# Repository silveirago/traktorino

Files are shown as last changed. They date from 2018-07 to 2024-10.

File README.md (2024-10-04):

# Traktorino

Welcome to the Traktorino project! The Traktorino is a low-cost, DIY MIDI controller for DJs. It can control any software that accepts MIDI, such as Traktor, Serato, or Ableton Live. This project is open-source, so you can download all the files for the schematics, enclosure, and code to build one yourself.

## Table of Contents
- [Introduction](#introduction)
- [Parts List](#parts-list)
- [Assembly Instructions](#assembly-instructions)
- [Programming the Arduino](#programming-the-arduino)
- [Setting Up MIDI](#setting-up-midi)
- [Enclosure Assembly](#enclosure-assembly)
- [Troubleshooting](#troubleshooting)
- [Support and Contributions](#support-and-contributions)

## Introduction
Watch the video series on how to build your Traktorino:
1. [Video 1: Introduction and Assembly](https://youtu.be/pawsvbFrXVM)
2. [Video 2: Programming the Arduino](https://youtu.be/B8oFYNJLdgw)
3. [Video 3: Setting Up MIDI](https://youtu.be/18OKo9sQ_s0)
4. [Video 4: Enclosure Assembly](https://youtu.be/xLqzVqaUnkY)

## Parts List
- 1x Traktorino PCB
- 1x Arduino Uno ATmega16U2
- 11x b10k vertical rotary pots
- 3x b10k slide pots - 45mm - 30mm travel (C3031N-1A2-B10K-GP)
- 1x Rotary Encoder
- 2x cd4067 be multiplexers
- 3x 74hc595 bit shifters
- 13x tactile buttons 6x6x9
- 24x 220ohm resistors 
- 1x 1k resistor
- 11x 3mm blue leds 
- 10x 3mm green leds
- 2x 3mm yellow leds
- 2x 3mm red leds

### Parts suggestion

- **Pot 25mm**
https://lcsc.com/product-detail/Potentiometers-Variable-Resistors_ALPS-Electric-RK09D1130C2P_C361173.html

- **Encoder 25mm**
https://www.mouser.com/ProductDetail/Bourns/PEC12R-4025F-N0024?qs=Zq5ylnUbLm4HSBD7%2FFgU%2FA%3D%3D

- **Encoder 20mm**
https://www.mouser.com/ProductDetail/Bourns/PEC11H-4120F-S0020?qs=7MVldsJ5Uaxh8cksqYCfvg%3D%3D 20mm

- **Slide Pot**
https://www.sparkfun.com/products/11621

## Assembly Instructions
1. **Resistors**: Insert and solder the 220 ohm resistors. Place a 1k resistor in the specified position.
2. **Arduino Pin Headers**: Solder the pin headers to the Arduino and snap it onto the PCB.
3. **Multiplexers and Bit Shifters**: Solder these components onto the PCB.
4. **LEDs**: Ensure correct polarity and solder the LEDs.
5. **Tactile Buttons**: Solder the tactile buttons, ensuring correct orientation.
6. **Potentiometers**: Solder the slide and rotary potentiometers.
7. **Rotary Encoder**: Solder the rotary encoder.

## Programming the Arduino
1. Download and install the [Arduino IDE](https://www.arduino.cc/en/software).
2. Clone the Traktorino GitHub repository: `git clone https://github.com/your-repo/traktorino`.
3. Open the Arduino IDE and load the Traktorino code.
4. Install the required libraries: ShiftPWM, MIDI, Multiplexer4067, Thread, and Encoder.
5. Verify the code and upload it to the Arduino Uno.

## Setting Up MIDI
1. **USB MIDI Compatibility**: Use an Arduino Uno with the ATmega16U2 for true USB MIDI compatibility.
2. **DFU Programmer**: Download and install the DFU programmer.
3. **Upload Firmware**: Use the provided `.hex` file to flash the firmware to the ATmega16U2.
4. **Test MIDI**: Use a DAW or MIDI monitoring software to test the MIDI signals from the Traktorino.

## Enclosure Assembly
1. Assemble the plywood enclosure using the provided PDF files.
2. Install the diffusers, spacers, and screws as specified.
3. Attach the button caps and potentiometer knobs.

## Troubleshooting
- If the Traktorino is not functioning, use a multimeter to check for connectivity issues.
- Verify that all components are correctly soldered and oriented.

## Support and Contributions
- Subscribe to the [YouTube channel](https://www.youtube.com/channel/UCyqCwyBJ98fR-CPoyXUxY5w) for updates and tutorials.
- Purchase a Traktorino kit from our store. (Out of stock)
- Check out the [DIY MIDI Controller Workshop](https://go.musiconerd.com/diy-midi-controller-workshop) for more in-depth learning.

## Code Explanation

### PWM Bit Shifter
The code uses a PWM bit shifter for controlling LEDs:
- `ShiftPWM_latchPin`: Set to pin 8.
- To avoid using the SPI port and change the pin numbers, uncomment `#define SHIFTPWM_NOSPI` and set `ShiftPWM_dataPin` and `ShiftPWM_clockPin`.
- `ShiftPWM_invertOutputs`: Set to `false`. Change to `true` if your LEDs turn on when the pin is low.
- `ShiftPWM_balanceLoad`: Set to `false`. Set to `true` to distribute current peaks.

### Libraries
The following libraries are included:
- **ShiftPWM** for PWM control.
- **MIDI** by Forty Seven Effects for MIDI communication.
- **Multiplexer4067** for handling the CD4067 multiplexer.
- **Thread** and **ThreadController** by Ivan Seidel for managing multiple tasks.
- **Encoder** by Paul Stoffregen for handling rotary encoders.

### Buttons
- `muxNButtons`: Number of digital inputs used in the multiplexer.
- `NButtons`: Number of direct digital inputs used.
- `muxButtonPin` and `buttonPin`: Arrays to store the pins used for buttons.

### Debounce
- `lastDebounceTime` and `debounceDelay`: Used to handle debounce for button presses.

### Potentiometers
- `NPots`: Number of analog inputs used.
- `muxPotPin`: Array to store the pins used for potentiometers.

### Potentiometer Reading
- `TIMEOUT`: Time the potentiometer will be read after exceeding `varThreshold`.
- `varThreshold`: Threshold for potentiometer signal variation.

### Encoder
- `myEnc`: Instance of the `Encoder` library using pins 3 and 2.
- `oldPosition`: Previous position of the encoder.

### MIDI Configuration
- `midiCh`, `note`, and `cc`: MIDI channel, note, and CC configurations.

### LEDs
- Configuration for controlling 24 LEDs with PWM.
- VU meter and button LED pins are defined.

### Multiplexer
- Instances of `Multiplexer4067` for pots and buttons.

### Threads
- `ThreadController` for managing tasks.
- Separate threads for reading potentiometers and buttons.

### Setup and Loop
In `setup()`, the serial communication is initialized, MIDI thru is turned off, multiplexers and LEDs are initialized, and threads are configured.

In `loop()`, the main tasks such as reading MIDI, encoder, and running threads are handled.

### Functions
- `readButtons()`: Reads button states and sends MIDI note messages.
- `readPots()`: Reads potentiometer states and sends MIDI control change messages.
- `readEncoder()`: Reads encoder values and sends MIDI control change messages.
- `handleControlChange()`, `handleNoteOn()`, and `handleNoteOff()`: Handle LED feedback for MIDI control changes and note messages.

## Usage
- Connect your Arduino and load the provided code.
- Ensure all components (buttons, potentiometers, LEDs) are connected to the specified pins.
- Install the required libraries mentioned above.
- Upload the code to your Arduino and start using your Traktorino MIDI controller with your favorite DJ software.

Feel free to modify the code and configurations to fit your specific needs. Happy DJing!

---

**Author**: Gustavo Silveira

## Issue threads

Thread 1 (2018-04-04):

Electronics sources

jvegaf, 2018-04-04:
Hi, can you add the electronics source project files on the project ?

Thanks !

ivnagst, 2018-05-15:
The project is awesome... But if you include more 2 channels and effects options... Removes the horizontal fadder, input microphone plug, master volume...

jvegaf, 2018-05-15:
maybe fork the project and through reverse engineering we could get the schematics

silveirago, 2018-05-17:
I will work more on it on July and will release a more complete material of
it!

2018-05-15 5:27 GMT-07:00 Jose Vega <notifications@github.com>:

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

--
Gustavo Silveira
Composer / Multimedia Artist
www.gustavosilveira.net

ameer157, 2018-05-17:
@silveirago I already managed to switch to the MidiUSB library and add multiple encoders as well as receiving 'MIDI Out' feedback from Traktor to light up LEDs 👍

stroblme, 2019-05-25:
Hi, anything new regarding the source files?

jvegaf, 2019-06-02:
> Hi, anything new regarding the source files?

the guy missed us, don't believe that releease the electronic source files....

jvegaf, 2021-01-31:
Thanks @silveirago

Closed 2021-01-31.

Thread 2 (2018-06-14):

Add Bill of Material and PCB project source files

sebastianeferrer, 2018-06-14:
Hi, it is great project I would like to colaborate it would be great if you share PCB project source files if not I can help you to export it to an open source software like kicad. Thank you again for sharing this with us!

silveirago, 2018-06-14:
Hi, I'm still bring in the project, that's why I didn't release everything
properly. I hope to have everything, plus tutorials by August. So, may I
contact you later for help with that?

2018-06-13 21:51 GMT-04:00 sebastianeferrer <notifications@github.com>:

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

--
Gustavo Silveira
Composer / Multimedia Artist
www.gustavosilveira.net

sebastianeferrer, 2018-06-15:
Yes, of course! It would be a pleasure.

DanBendavid, 2018-06-30:
Ciao Silvio
Dan here. Your project is so elegant and very powerful. I have one question regarding the encoder.
You have not included a debouncing hardware (i.e., C10nF and R10KO) ? is that because the MIDI has its own debouncing "mechanism" ?
Gracie mille for making this Open.

silveirago, 2018-06-30:
Hi, the Encoder library is really good and takes care of it. It works pretty flawlessly!

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

spotlesscoder, 2025-03-16:
can this issue be closed now?

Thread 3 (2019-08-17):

Mixxx profile

arthurlutz, 2019-08-17:
It would be nice to be able to use traktorino with a Mixxx https://www.mixxx.org/ the open source DJ software.

I've started a profile by detecting the Input Mapping, but am having trouble with the output mapping (turn on and off LEDs)

arthurlutz, 2019-08-17:
Here is  the "initial" config file I've started : https://gist.github.com/arthurlutz/25ea0970a9d26ba0394d54f1b79cdaea

Put it in `$HOME/.mixxx/controllers/`

arthurlutz, 2019-08-17:
Here is the Mixxx documentation for this mapping, https://mixxx.org/wiki/doku.php/midi_controller_mapping_file_format

Unfortunatelly the Traktor XML file https://github.com/silveirago/traktorino/blob/master/Traktor/Traktorino.tsi is unreadable, I was hoping to get information from there. If anyone has a way to decrypt/decode it, that would be greate, or a screenshot of the configuration in traktor would be nice too.

WieFel, 2019-09-28:
Thanks for your config!
I have the exact same problem. My LEDs are not lighting up.

Additionally, my faders are not working properly when trying to "learn" them with Mixxx. E.g. when the physical fader is positioned exactly in the center, the fader in Mixxx is quite far on the left side... I don't know if that is related to the potentiometers I used or to Mixxx. Have you experienced similar problems?

dulouie, 2020-11-10:
Hi guys, I created a javascript profile for Mixxx some time ago. All sliders, pots and also the LEDs work. Unfortunately there are still a few bugs. For example, sometimes you have to click into the list again when selecting a song. I hope I will have more time to develop further soon.
https://github.com/dulouie/traktorino/tree/mixxxscript/Mixxx

arthurlutz, 2020-11-11:
Awesome @dulouie it works great ! (not sure what what "shift" does, and filter on/off seems to not work in my setup)

To get it working I had to `cp Traktorino.midi.xml ~/.mixxx/controllers/Traktorino_MIDI_1.midi.xml` (not sure why it needs the `_MIDI_1` addition).

I think these files should be shipped directly with Mixxx so traktorino works out of the box, how would you feel about submitting them to https://github.com/mixxxdj/mixxx/tree/main/res/controllers ? Do you  want help with that ?

dulouie, 2020-11-14:
I think the shift-button allows a double assignment of the other buttons, you can theoretically control 4 decks, but I don't use it.
Yes, I noticed the "_MIDI_1" but I have no idea why it only works with that.
My goal is also a pull request to Mixx, but I want to fix the remaining bugs and clean up a bit, the logic to create the decks is not quite clean yet. If you like you can help me. I have the new branch for a PR here:
https://github.com/dulouie/mixxx/tree/traktorino/

WieFel, 2020-11-14:
@arthurlutz @dulouie really cool guys!! 👏🏼

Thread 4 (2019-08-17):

Provide test code (MIDI or Arduino) to test out the LEDs once the assembly is finished

arthurlutz, 2019-08-17:
Once the assembly is finished it would be nice to have a test program to test out all the LEDs, two solutions could be used :

* some sort of python script or other that talks to midi and turns on and off the LEDs by sending MIDI signales

* an arduino sketch that goes through all the LEDs and turns them on and off and prints out some debug information on the serial port.

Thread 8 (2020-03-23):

MIDI Input gets echoed onto MIDI Output, create infinite send/receive loop in dj software

rasprague, 2020-03-23:
CC messages on MIDI Input are being echoed back out onto MIDI Output. This causes an infinite send/receive loop in the dj software.

Issue recreated in DJ Player Pro on iOS during led CC mapping.

Issue recreated in MIDI-OX on Windows 10, when both Traktorino MIDI Input and Output are opened

rasprague, 2020-03-24:
I think I fixed this one, check put pull request https://github.com/silveirago/traktorino/pull/12

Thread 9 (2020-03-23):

Browse Encode click not mapped to any MIDI output message

rasprague, 2020-03-23:
Clicking the Browse encoder does not result in a MIDI message being send out.

Is the encoder click currently wired to a pin via the PCB? If so, where does it go? If not, a possible workaround would to be to wire it up to a free digital pin on the Arduino (hacking!), and read that digital pin from the code.

rasprague, 2020-03-24:
got it working!

pull reqeust https://github.com/silveirago/traktorino/pull/11

Gypsyocruzz, 2023-04-02:
hello rasprague. Im making this porject can you tell me if you also had shots in the pcb or components? Cos in the traktor software the pots and others others components doesnt stops to send midi signals. So i cant control the controller in a proper way

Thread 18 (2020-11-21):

Issues with some pots and midi data range

edy80y, 2020-11-21:
Hi All,

I've just built a Traktorino from scratch and as per the title I need help.

1. The following potentiometers are not registering:
- Ch1 fader
- Ch2 gain
- Ch2 eq high
- Ch2 eq mid

2. Using Midi Monitor, the working pots have data values ranging between 64-126 (i.e. only 50% range).  In other words the entire range of the potentiometers are only effecting from centre to max, and this translates the same way in Traktor Pro, for example: Turning Ch1 Eq Low only moves between centre and max, Ch2 fader only moves from 50% to 100% in the software.

I noticed at the bottom of the PCB there are points for test (continuity etc?).  Is there any documentation on how to use them and what values to expect during trouble shooting? I do own a multimeter, and any help would be appreciated.

lastly, what's the best way to reduce the brightness of the leds? Can i replace the resisters with a higher value?

Cheers,
Eddie

Gypsyocruzz, 2023-04-02:
hello. Im making this porject can you tell me if you also had shots in the pcb or components? Cos in the traktor software the pots and others others components doesnt stops to send midi signals. So i cant control the controller in a proper way

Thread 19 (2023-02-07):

MIDI ERROR IN CODE, PLS NEED HELP

JotaMichas, 2023-02-07:
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

D:\Arduino\traktorino-master\Code\Traktorino\Traktorino.ino: In function 'void setup()':
D:\Arduino\traktorino-master\Code\Traktorino\Traktorino.ino:115:3: error: 'MIDI' was not declared in this scope
   MIDI.turnThruOff();
   ^~~~
D:\Arduino\traktorino-master\Code\Traktorino\Traktorino.ino:115:3: note: suggested alternative: 'MISO'
   MIDI.turnThruOff();
   ^~~~
   MISO
D:\Arduino\traktorino-master\Code\Traktorino\Traktorino.ino: In function 'void loop()':
D:\Arduino\traktorino-master\Code\Traktorino\Traktorino.ino:176:3: error: 'MIDI' was not declared in this scope
   MIDI.read();
   ^~~~
D:\Arduino\traktorino-master\Code\Traktorino\Traktorino.ino:176:3: note: suggested alternative: 'MISO'
   MIDI.read();
   ^~~~
   MISO
D:\Arduino\traktorino-master\Code\Traktorino\Traktorino.ino: In function 'void readButtons()':
D:\Arduino\traktorino-master\Code\Traktorino\Traktorino.ino:214:11: error: 'MIDI' was not declared in this scope
           MIDI.sendNoteOn(note + i, 127, midiCh); // envia NoteOn(nota, velocity, canal midi)
           ^~~~
D:\Arduino\traktorino-master\Code\Traktorino\Traktorino.ino:214:11: note: suggested alternative: 'MISO'
           MIDI.sendNoteOn(note + i, 127, midiCh); // envia NoteOn(nota, velocity, canal midi)
           ^~~~
           MISO
D:\Arduino\traktorino-master\Code\Traktorino\Traktorino.ino:221:11: error: 'MIDI' was not declared in this scope
           MIDI.sendNoteOn(note + i, 0, midiCh);
           ^~~~
D:\Arduino\traktorino-master\Code\Traktorino\Traktorino.ino:221:11: note: suggested alternative: 'MISO'
           MIDI.sendNoteOn(note + i, 0, midiCh);
           ^~~~
           MISO
D:\Arduino\traktorino-master\Code\Traktorino\Traktorino.ino: In function 'void readPots()':
D:\Arduino\traktorino-master\Code\Traktorino\Traktorino.ino:261:9: error: 'MIDI' was not declared in this scope
         MIDI.sendControlChange(cc + i, map(potCState[i], 0, 1023, 0, 127), 11); // envia Control Change (numero do CC, valor do CC, canal midi)
         ^~~~
D:\Arduino\traktorino-master\Code\Traktorino\Traktorino.ino:261:9: note: suggested alternative: 'MISO'
         MIDI.sendControlChange(cc + i, map(potCState[i], 0, 1023, 0, 127), 11); // envia Control Change (numero do CC, valor do CC, canal midi)
         ^~~~
         MISO
D:\Arduino\traktorino-master\Code\Traktorino\Traktorino.ino: In function 'void readEncoder()':
D:\Arduino\traktorino-master\Code\Traktorino\Traktorino.ino:288:5: error: 'MIDI' was not declared in this scope
     MIDI.sendControlChange(14, encoderValue, 1);
     ^~~~
D:\Arduino\traktorino-master\Code\Traktorino\Traktorino.ino:288:5: note: suggested alternative: 'MISO'
     MIDI.sendControlChange(14, encoderValue, 1);
     ^~~~
     MISO
Multiple libraries were found for "MIDI.h"
  Used: C:\Users\Jota\Documents\Arduino\libraries\MIDI_Library
  Not used: C:\Users\Jota\Documents\Arduino\libraries\arduino_midi_library-master
exit status 1

Compilation error: 'MIDI' was not declared in this scope

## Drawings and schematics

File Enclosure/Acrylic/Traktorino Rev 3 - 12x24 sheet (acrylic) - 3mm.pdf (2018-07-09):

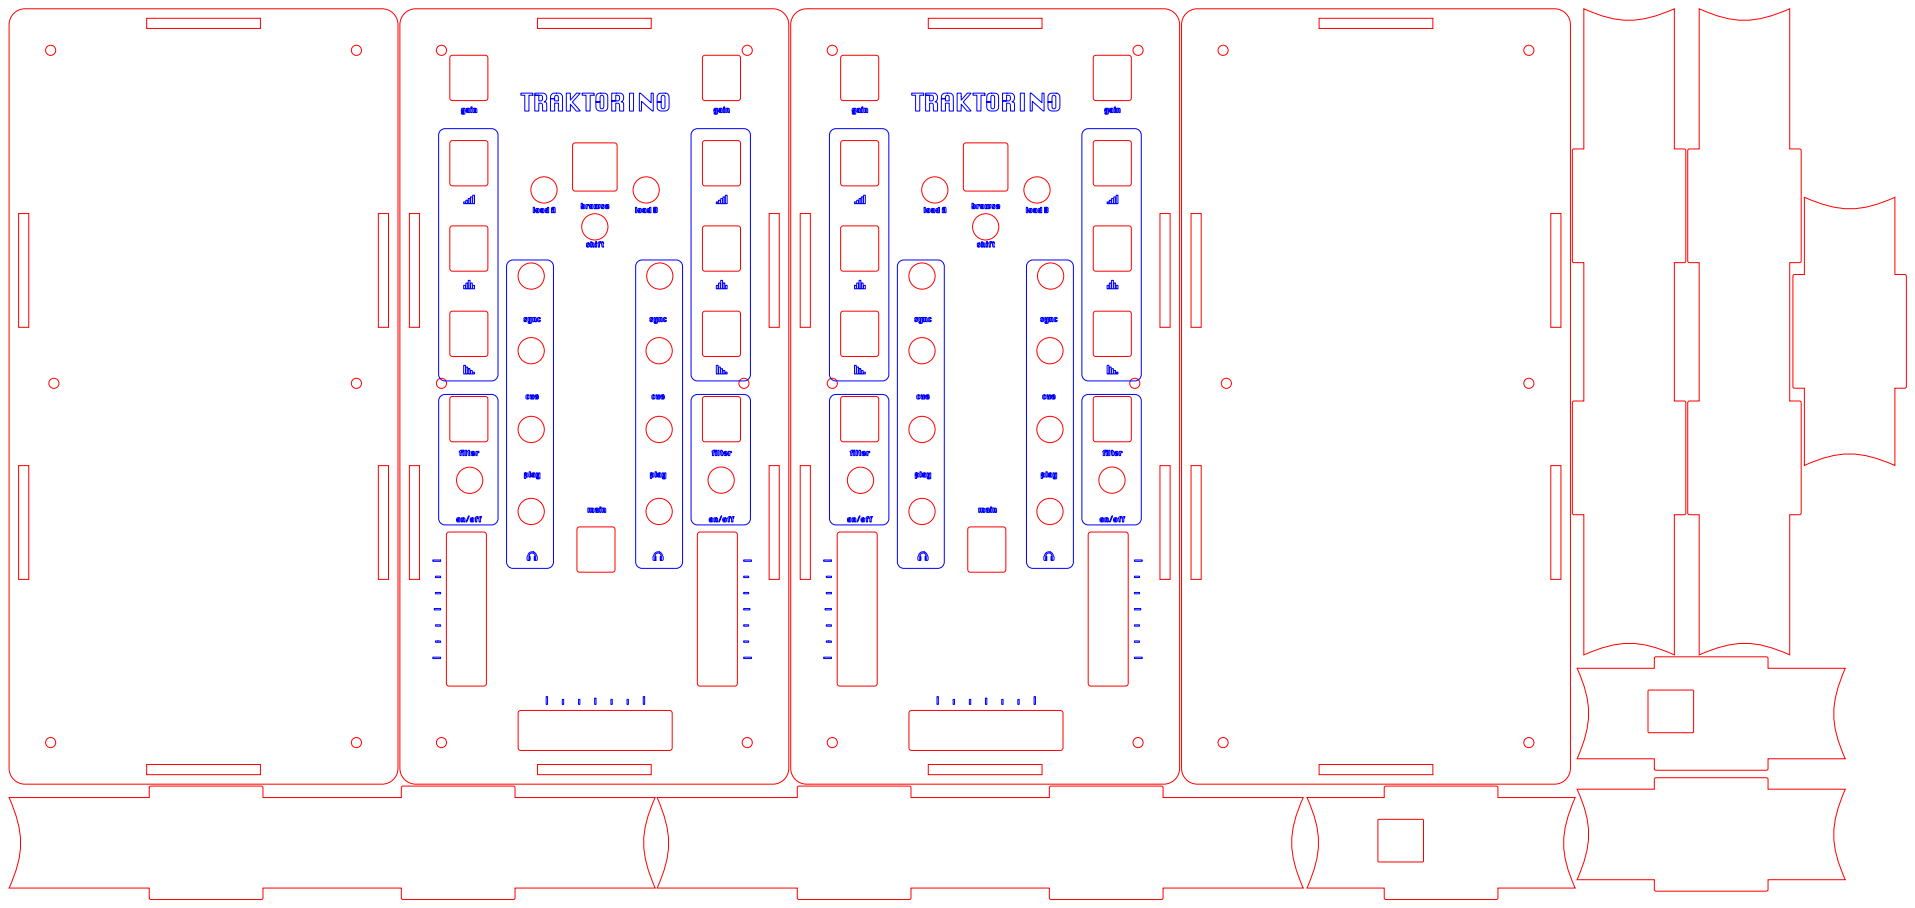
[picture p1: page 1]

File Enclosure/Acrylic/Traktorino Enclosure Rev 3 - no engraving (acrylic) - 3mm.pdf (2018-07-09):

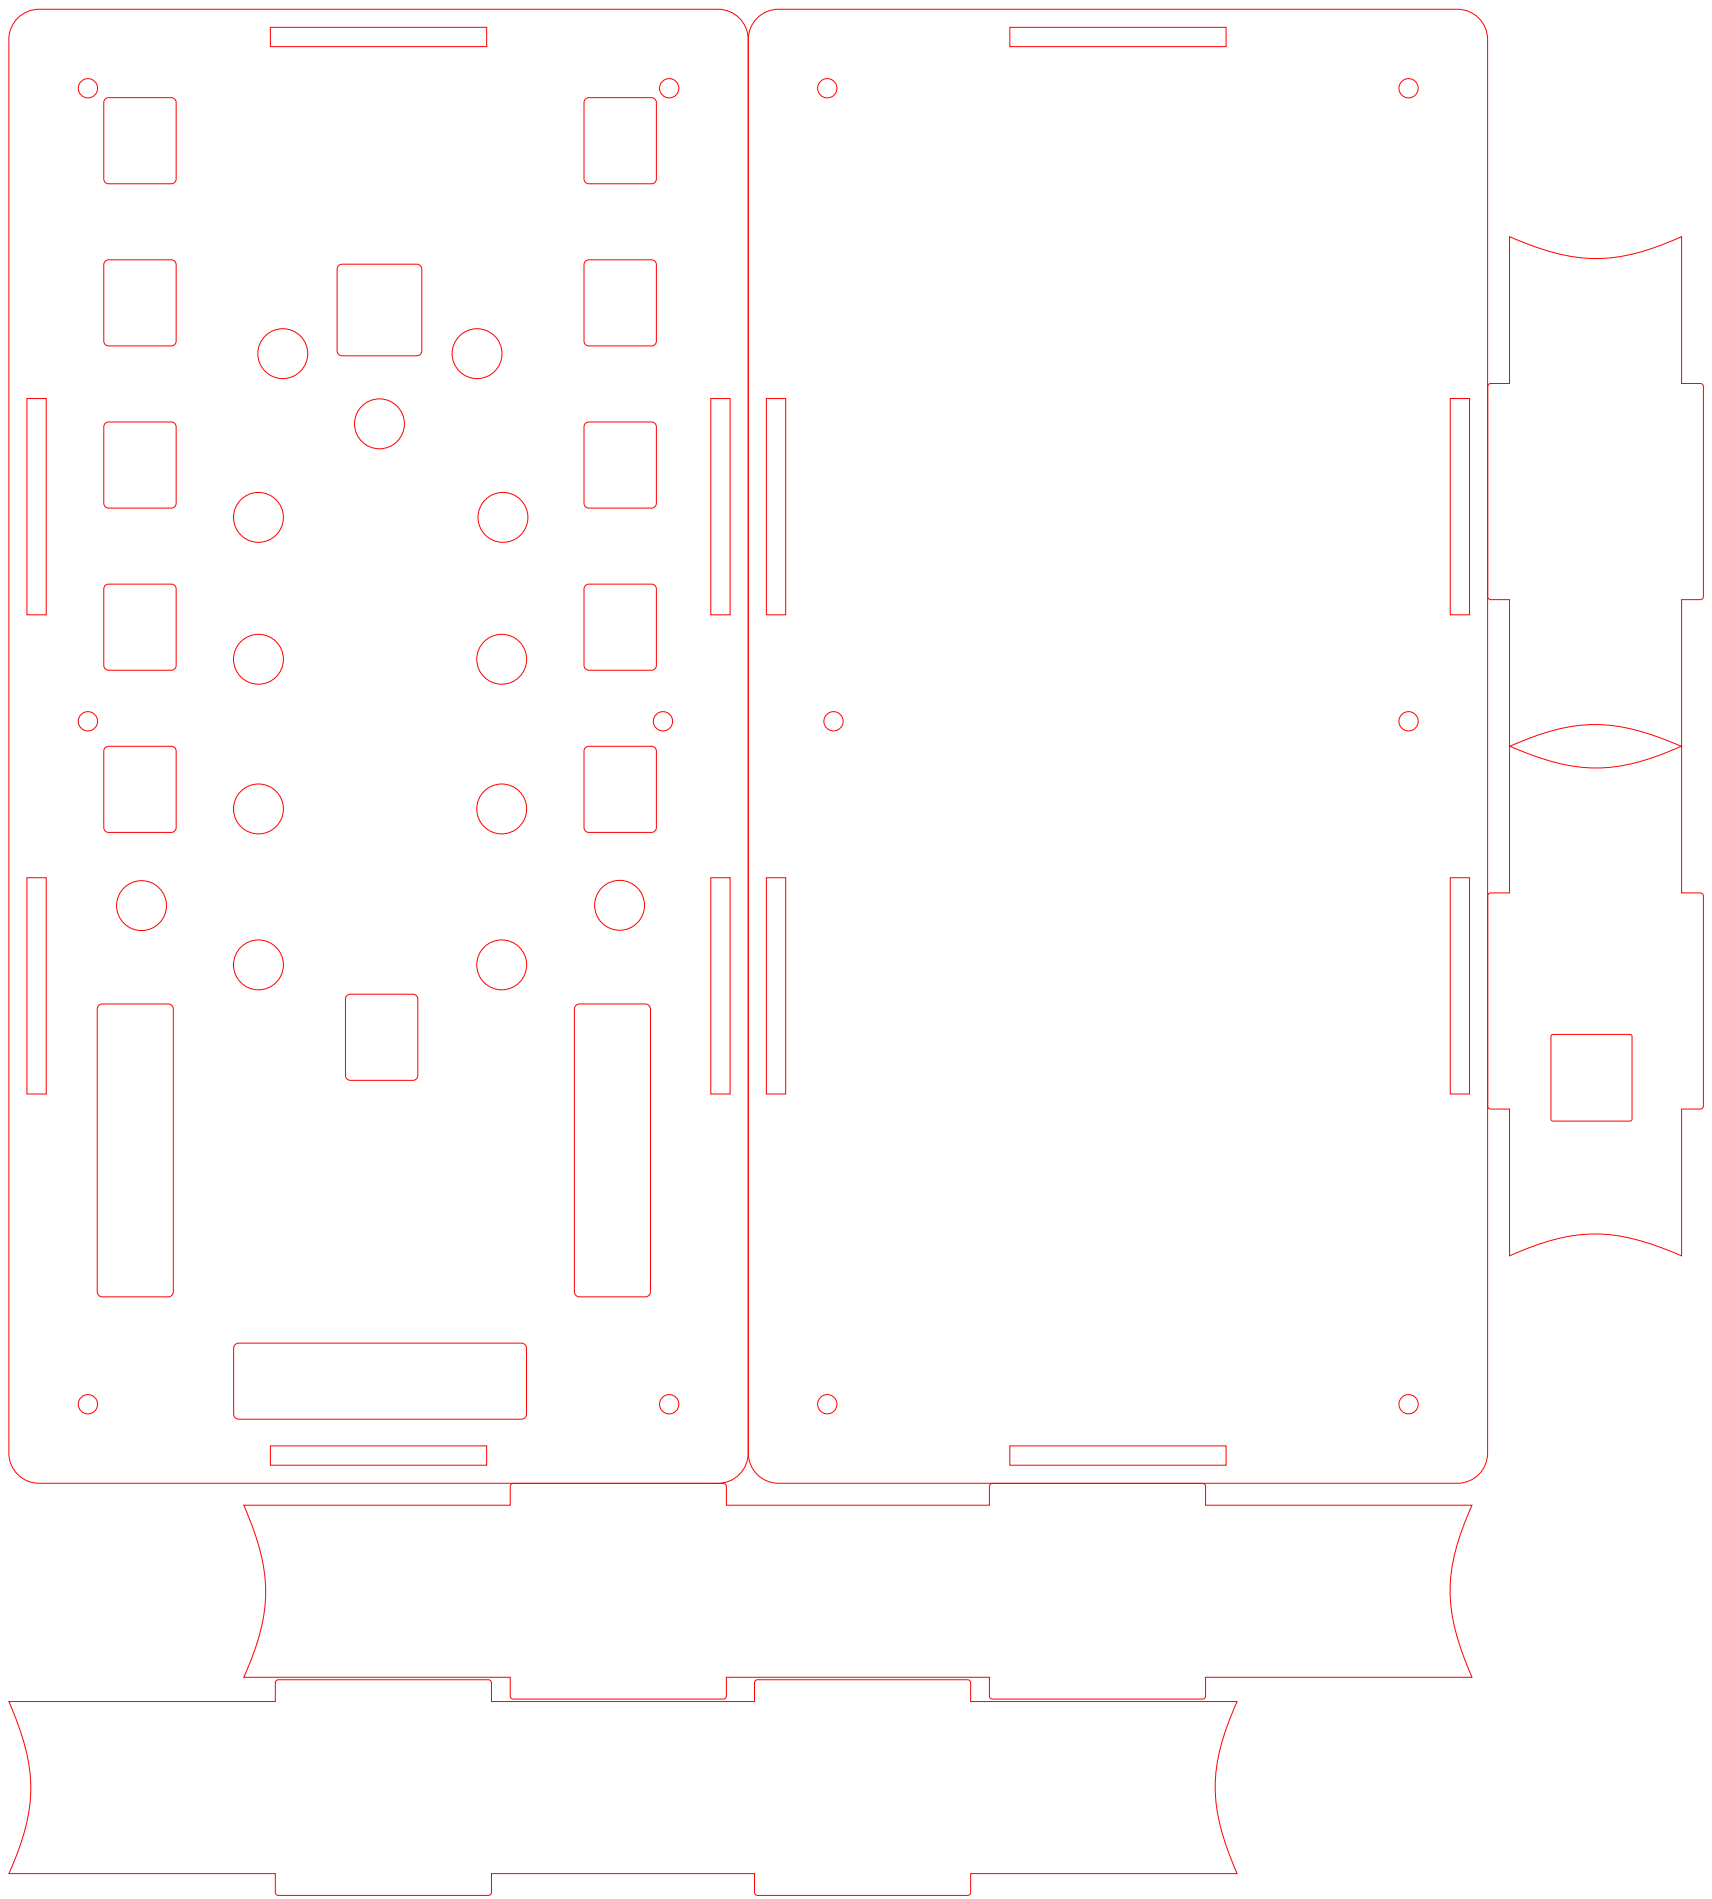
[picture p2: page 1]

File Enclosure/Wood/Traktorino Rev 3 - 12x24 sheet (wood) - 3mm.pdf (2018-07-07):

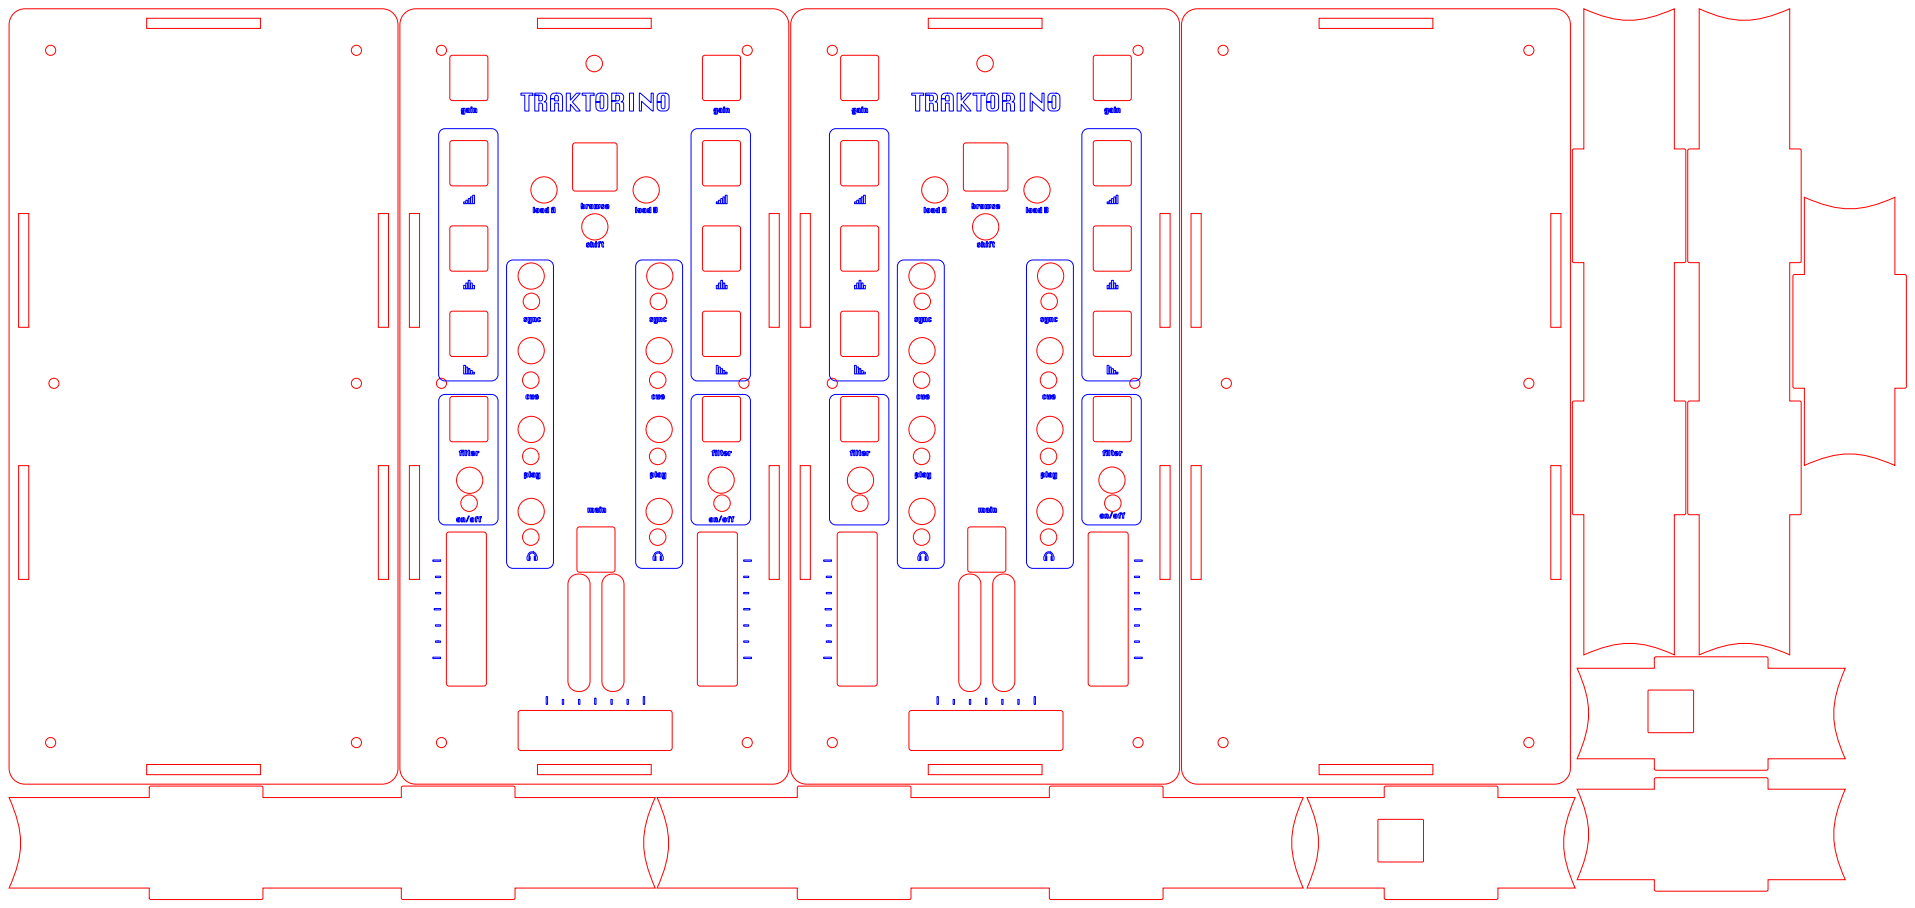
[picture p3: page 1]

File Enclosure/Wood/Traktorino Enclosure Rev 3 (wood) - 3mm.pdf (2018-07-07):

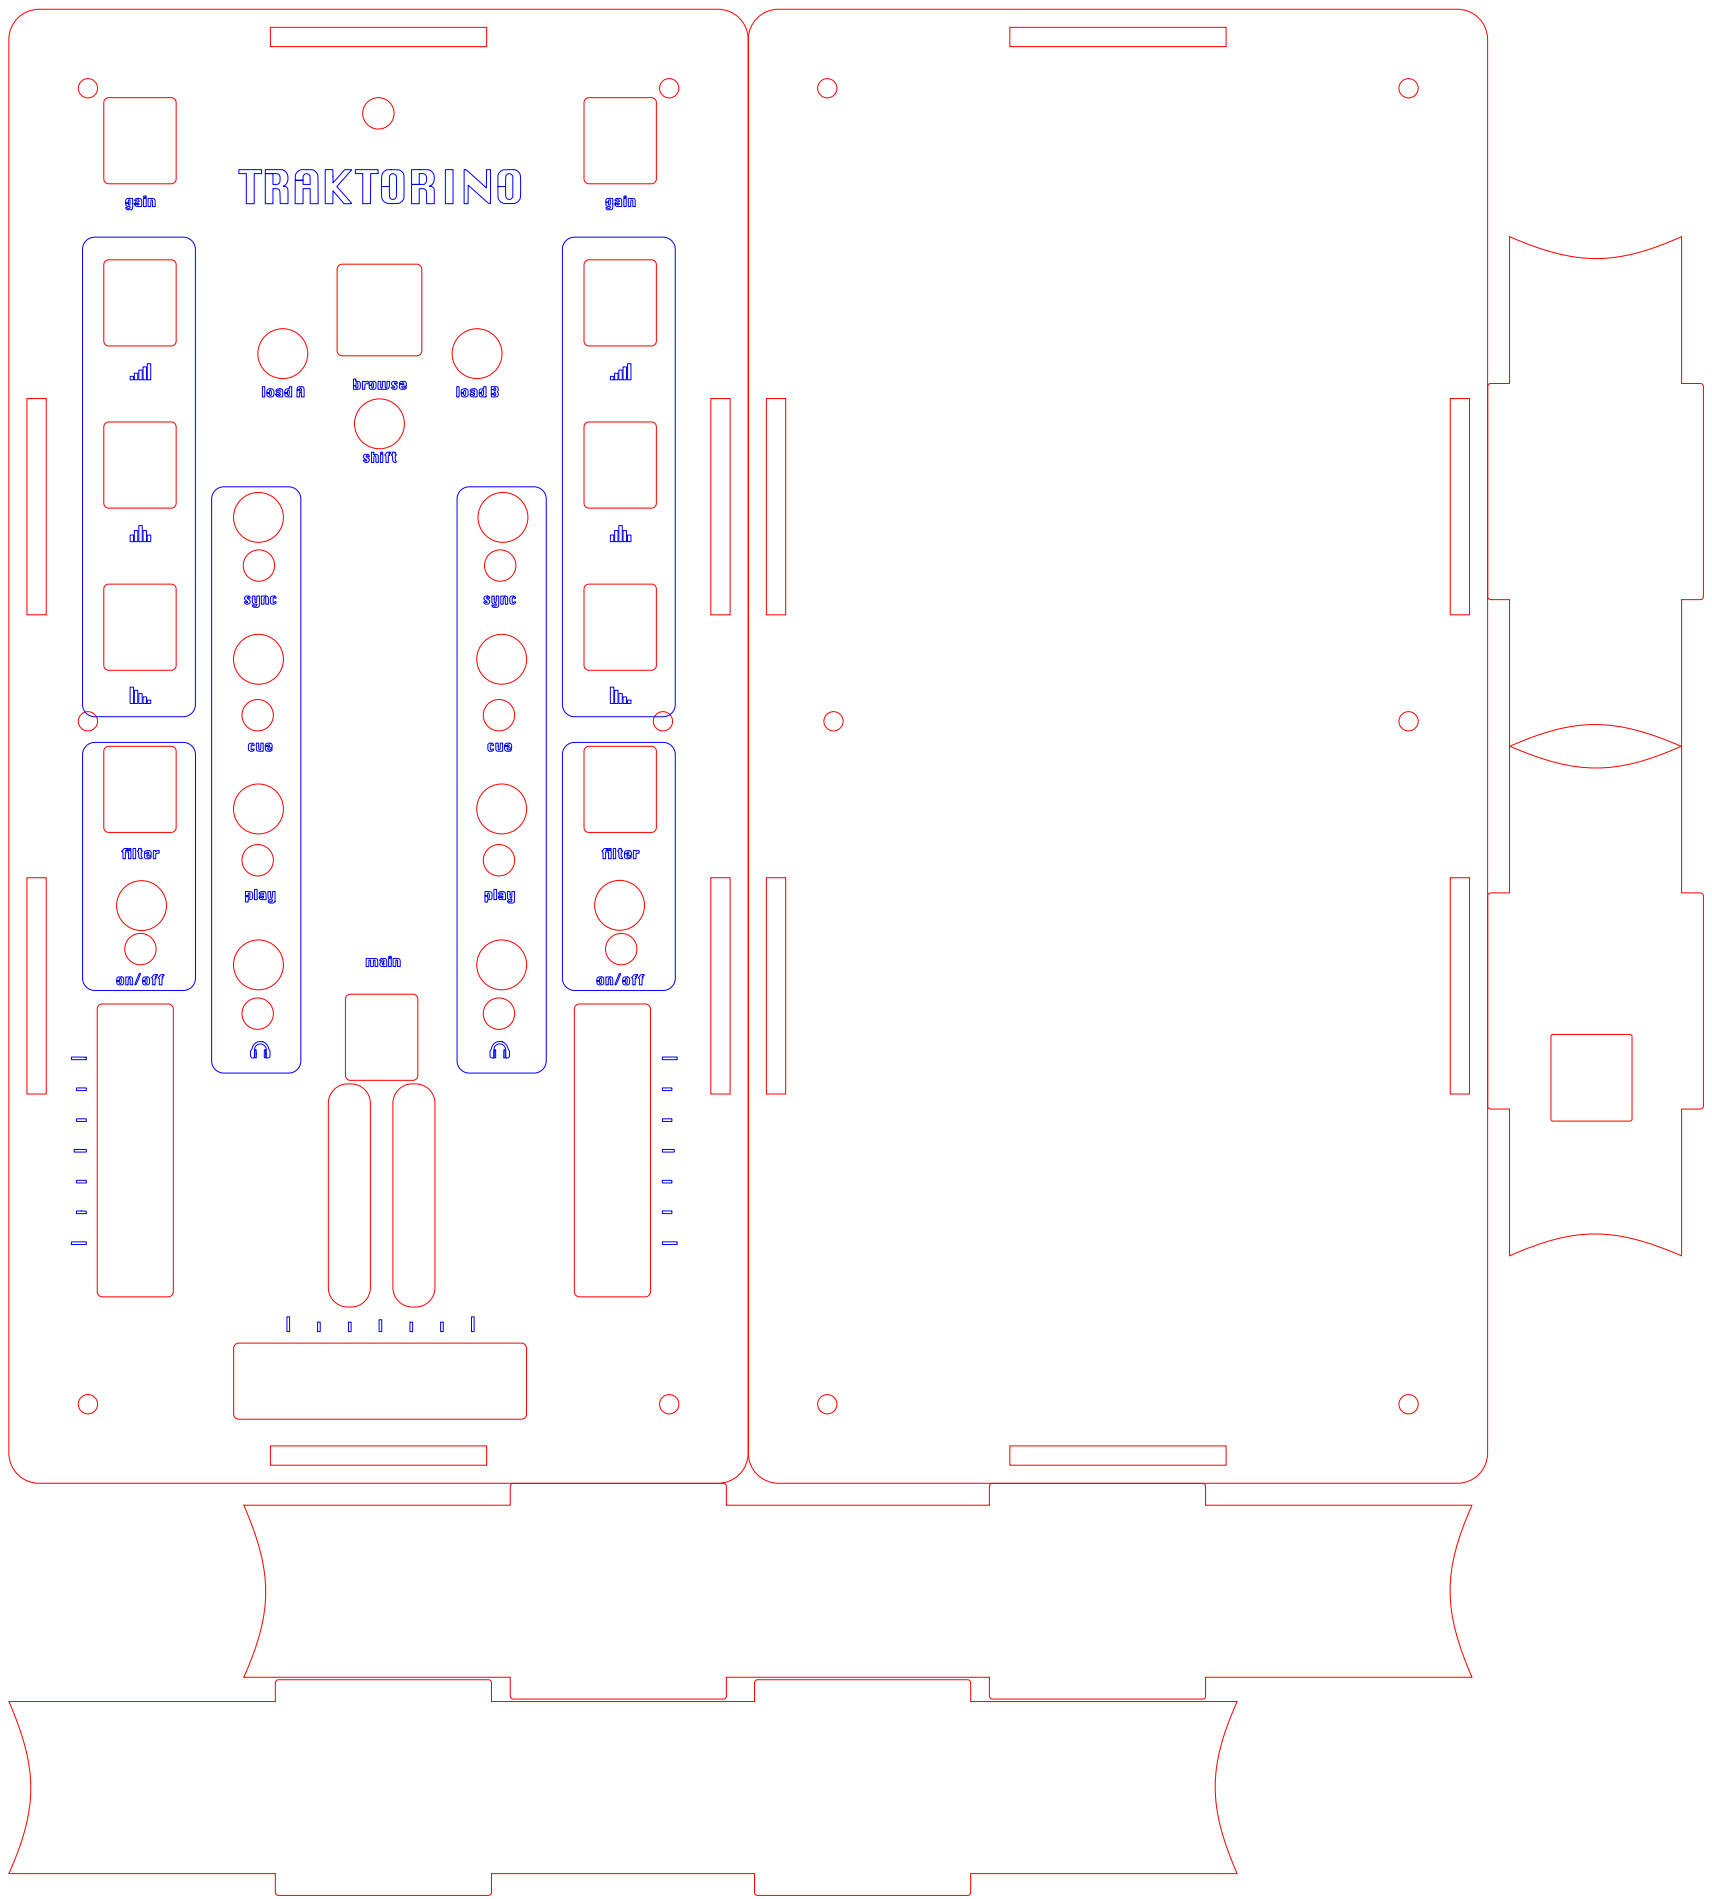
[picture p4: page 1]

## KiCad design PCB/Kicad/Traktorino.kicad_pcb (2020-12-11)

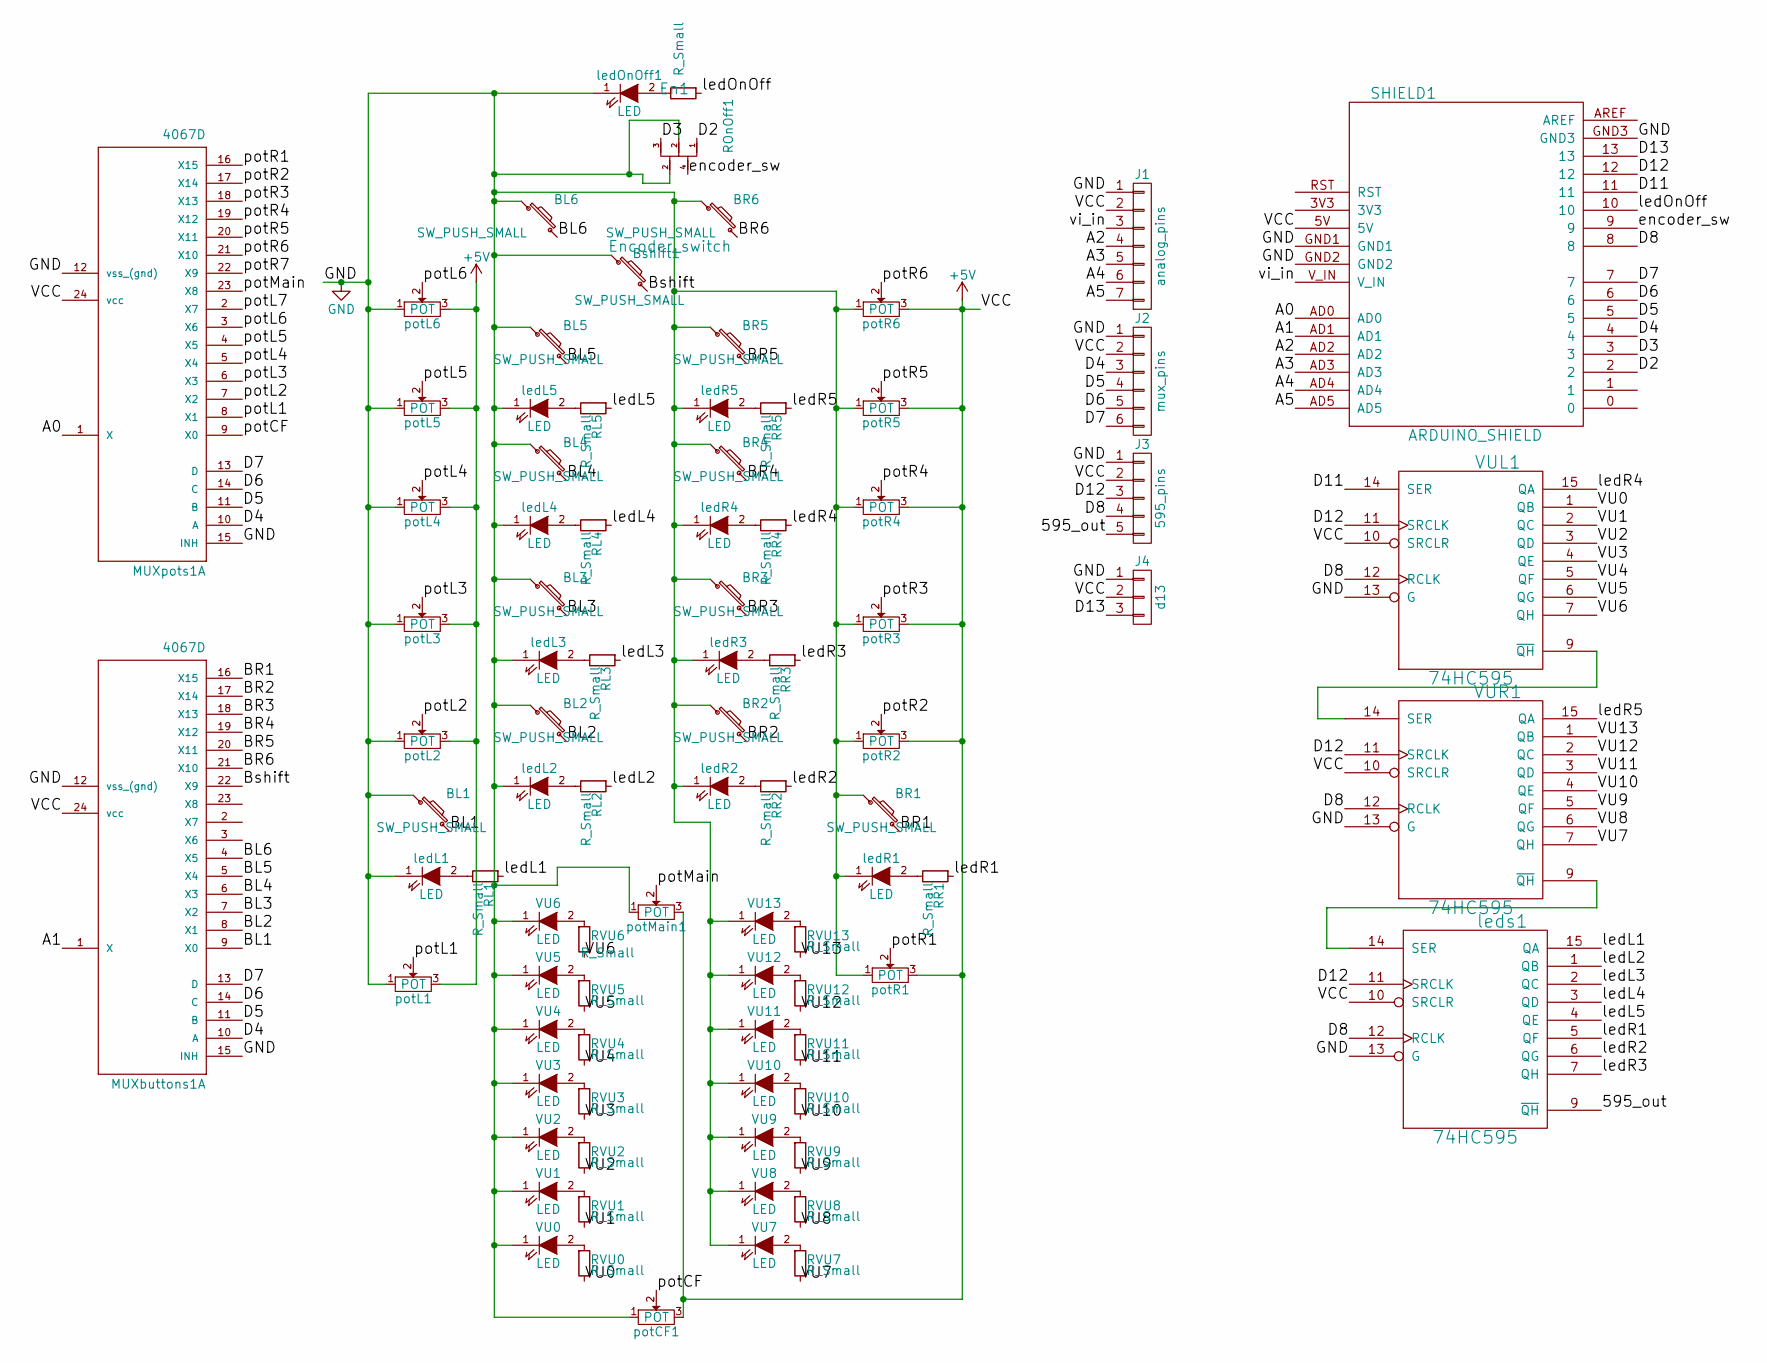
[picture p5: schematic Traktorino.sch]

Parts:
BL1, BL2, BL3, BL4, BL5, BL6: SW_PUSH_SMALL; SW_tactile
BR1, BR2, BR3, BR4, BR5, BR6: SW_PUSH_SMALL; SW_tactile
Bshift1: SW_PUSH_SMALL; SW_tactile
En1: Encoder_switch; SF-ROTARY-ENCODER_gus
J1: analog_pins; Pin_Header_Straight_1x07_Pitch2.54mm
J2: mux_pins; Pin_Header_Straight_1x06_Pitch2.54mm
J3: 595_pins; Pin_Header_Straight_1x05_Pitch2.54mm
J4: d13; Pin_Header_Straight_1x03_Pitch2.54mm
MUXbuttons1: 4067D; 40xx-DIL24-6
MUXpots1: 4067D; 40xx-DIL24-6
RL1, RL2, RL3, RL4, RL5: R_Small; Resistor_Horizontal_RM7mm
ROnOff1: R_Small; Resistor_Horizontal_RM7mm
RR1, RR2, RR3, RR4, RR5: R_Small; Resistor_Horizontal_RM7mm
RVU0, RVU1, RVU2, RVU3, RVU4, RVU5, RVU6, RVU7, RVU8, RVU9, RVU10, RVU11, RVU12, RVU13: R_Small; Resistor_Horizontal_RM7mm
SHIELD1: ARDUINO_SHIELD; ARDUINO_SHIELD_2_040pins
VU0, VU1, VU2, VU3, VU4, VU5, VU6, VU7, VU8, VU9, VU10, VU11, VU12, VU13: LED; LED-3MM
VUL1: 74HC595; DIL16
VUR1: 74HC595; DIL16
ledL1, ledL2, ledL3, ledL4, ledL5: LED; LED-3MM
ledOnOff1: LED; LED-3MM
ledR1, ledR2, ledR3, ledR4, ledR5: LED; LED-3MM
leds1: 74HC595; DIL16
potCF1: POT; Slide_Potentiometer
potL1: POT; Slide_Potentiometer
potL2, potL3, potL4, potL5, potL6: POT; Pot_vertical
potMain1: POT; Pot_vertical
potR1: POT; Slide_Potentiometer
potR2, potR3, potR4, potR5, potR6: POT; Pot_vertical

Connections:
+5V: J1.2, J2.2, J3.2, J4.2, MUXbuttons1.24 (vcc), MUXpots1.24 (vcc), SHIELD1.5V, VUL1.10 (SRCLR), VUL1.16 (VCC), VUR1.10 (SRCLR), VUR1.16 (VCC), leds1.10 (SRCLR), leds1.16 (VCC), potCF1.3, potL1.3, potL2.3, potL3.3, potL4.3, potL5.3, potL6.3, potMain1.3, potR1.3, potR2.3, potR3.3, potR4.3, potR5.3, potR6.3
/595_out: J3.5, leds1.9 (~QH)
/A0: MUXpots1.1 (X), SHIELD1.AD0
/A1: MUXbuttons1.1 (X), SHIELD1.AD1
/A2: J1.4, SHIELD1.AD2
/A3: J1.5, SHIELD1.AD3
/A4: J1.6, SHIELD1.AD4
/A5: J1.7, SHIELD1.AD5
/BL1: BL1.2, MUXbuttons1.9 (X0)
/BL2: BL2.2, MUXbuttons1.8 (X1)
/BL3: BL3.2, MUXbuttons1.7 (X2)
/BL4: BL4.2, MUXbuttons1.6 (X3)
/BL5: BL5.2, MUXbuttons1.5 (X4)
/BL6: BL6.2, MUXbuttons1.4 (X5)
/BR1: BR1.2, MUXbuttons1.16 (X15)
/BR2: BR2.2, MUXbuttons1.17 (X14)
/BR3: BR3.2, MUXbuttons1.18 (X13)
/BR4: BR4.2, MUXbuttons1.19 (X12)
/BR5: BR5.2, MUXbuttons1.20 (X11)
/BR6: BR6.2, MUXbuttons1.21 (X10)
/Bshift: Bshift1.2, MUXbuttons1.22 (X9)
/D2: En1.1, SHIELD1.2
/D3: En1.3, SHIELD1.3
/D4: J2.3, MUXbuttons1.10 (A), MUXpots1.10 (A), SHIELD1.4
/D5: J2.4, MUXbuttons1.11 (B), MUXpots1.11 (B), SHIELD1.5
/D6: J2.5, MUXbuttons1.14 (C), MUXpots1.14 (C), SHIELD1.6
/D7: J2.6, MUXbuttons1.13 (D), MUXpots1.13 (D), SHIELD1.7
/D8: J3.4, SHIELD1.8, VUL1.12 (RCLK), VUR1.12 (RCLK), leds1.12 (RCLK)
/D11: SHIELD1.11, VUL1.14 (SER)
/D12: J3.3, SHIELD1.12, VUL1.11 (SRCLK), VUR1.11 (SRCLK), leds1.11 (SRCLK)
/D13: J4.3, SHIELD1.13
/VU0: RVU0.2, VUL1.1 (QB)
/VU1: RVU1.2, VUL1.2 (QC)
/VU2: RVU2.2, VUL1.3 (QD)
/VU3: RVU3.2, VUL1.4 (QE)
/VU4: RVU4.2, VUL1.5 (QF)
/VU5: RVU5.2, VUL1.6 (QG)
/VU6: RVU6.2, VUL1.7 (QH)
/VU7: RVU7.2, VUR1.7 (QH)
/VU8: RVU8.2, VUR1.6 (QG)
/VU9: RVU9.2, VUR1.5 (QF)
/VU10: RVU10.2, VUR1.4 (QE)
/VU11: RVU11.2, VUR1.3 (QD)
/VU12: RVU12.2, VUR1.2 (QC)
/VU13: RVU13.2, VUR1.1 (QB)
/encoder_sw: En1.4, SHIELD1.9
/ledL1: RL1.1, leds1.15 (QA)
/ledL2: RL2.1, leds1.1 (QB)
/ledL3: RL3.1, leds1.2 (QC)
/ledL4: RL4.1, leds1.3 (QD)
/ledL5: RL5.1, leds1.4 (QE)
/ledOnOff: ROnOff1.1, SHIELD1.10
/ledR1: RR1.1, leds1.5 (QF)
/ledR2: RR2.1, leds1.6 (QG)
/ledR3: RR3.1, leds1.7 (QH)
/ledR4: RR4.1, VUL1.15 (QA)
/ledR5: RR5.1, VUR1.15 (QA)
/potCF: MUXpots1.9 (X0), potCF1.2
/potL1: MUXpots1.8 (X1), potL1.2
/potL2: MUXpots1.7 (X2), potL2.2
/potL3: MUXpots1.6 (X3), potL3.2
/potL4: MUXpots1.5 (X4), potL4.2
/potL5: MUXpots1.4 (X5), potL5.2
/potL6: MUXpots1.3 (X6), potL6.2
/potL7: MUXpots1.2 (X7)
/potMain: MUXpots1.23 (X8), potMain1.2
/potR1: MUXpots1.16 (X15), potR1.2
/potR2: MUXpots1.17 (X14), potR2.2
/potR3: MUXpots1.18 (X13), potR3.2
/potR4: MUXpots1.19 (X12), potR4.2
/potR5: MUXpots1.20 (X11), potR5.2
/potR6: MUXpots1.21 (X10), potR6.2
/potR7: MUXpots1.22 (X9)
/vi_in: J1.3, SHIELD1.V_IN
GND: BL1.1, BL2.1, BL3.1, BL4.1, BL5.1, BL6.1, BR1.1, BR2.1, BR3.1, BR4.1, BR5.1, BR6.1, Bshift1.1, En1.2, J1.1, J2.1, J3.1, J4.1, MUXbuttons1.12 (vss_(gnd)), MUXbuttons1.15 (INH), MUXpots1.12 (vss_(gnd)), MUXpots1.15 (INH), SHIELD1.GND1, SHIELD1.GND2, SHIELD1.GND3, VU0.1 (K), VU1.1 (K), VU2.1 (K), VU3.1 (K), VU4.1 (K), VU5.1 (K), VU6.1 (K), VU7.1 (K), VU8.1 (K), VU9.1 (K), VU10.1 (K), VU11.1 (K), VU12.1 (K), VU13.1 (K), VUL1.8 (GND), VUL1.13 (G), VUR1.8 (GND), VUR1.13 (G), ledL1.1 (K), ledL2.1 (K), ledL3.1 (K), ledL4.1 (K), ledL5.1 (K), ledOnOff1.1 (K), ledR1.1 (K), ledR2.1 (K), ledR3.1 (K), ledR4.1 (K), ledR5.1 (K), leds1.8 (GND), leds1.13 (G), potCF1.1, potL1.1, potL2.1, potL3.1, potL4.1, potL5.1, potL6.1, potMain1.1, potR1.1, potR2.1, potR3.1, potR4.1, potR5.1, potR6.1
unnamed: RL1.2, ledL1.2 (A)
unnamed: RL2.2, ledL2.2 (A)
unnamed: RL3.2, ledL3.2 (A)
unnamed: RL4.2, ledL4.2 (A)
unnamed: RL5.2, ledL5.2 (A)
unnamed: ROnOff1.2, ledOnOff1.2 (A)
unnamed: RR1.2, ledR1.2 (A)
unnamed: RR2.2, ledR2.2 (A)
unnamed: RR3.2, ledR3.2 (A)
unnamed: RR4.2, ledR4.2 (A)
unnamed: RR5.2, ledR5.2 (A)
unnamed: RVU0.1, VU0.2 (A)
unnamed: RVU1.1, VU1.2 (A)
unnamed: RVU2.1, VU2.2 (A)
unnamed: RVU3.1, VU3.2 (A)
unnamed: RVU4.1, VU4.2 (A)
unnamed: RVU5.1, VU5.2 (A)
unnamed: RVU6.1, VU6.2 (A)
unnamed: RVU7.1, VU7.2 (A)
unnamed: RVU8.1, VU8.2 (A)
unnamed: RVU9.1, VU9.2 (A)
unnamed: RVU10.1, VU10.2 (A)
unnamed: RVU11.1, VU11.2 (A)
unnamed: RVU12.1, VU12.2 (A)
unnamed: RVU13.1, VU13.2 (A)
unnamed: VUL1.9 (~QH), VUR1.14 (SER)
unnamed: VUR1.9 (~QH), leds1.14 (SER)

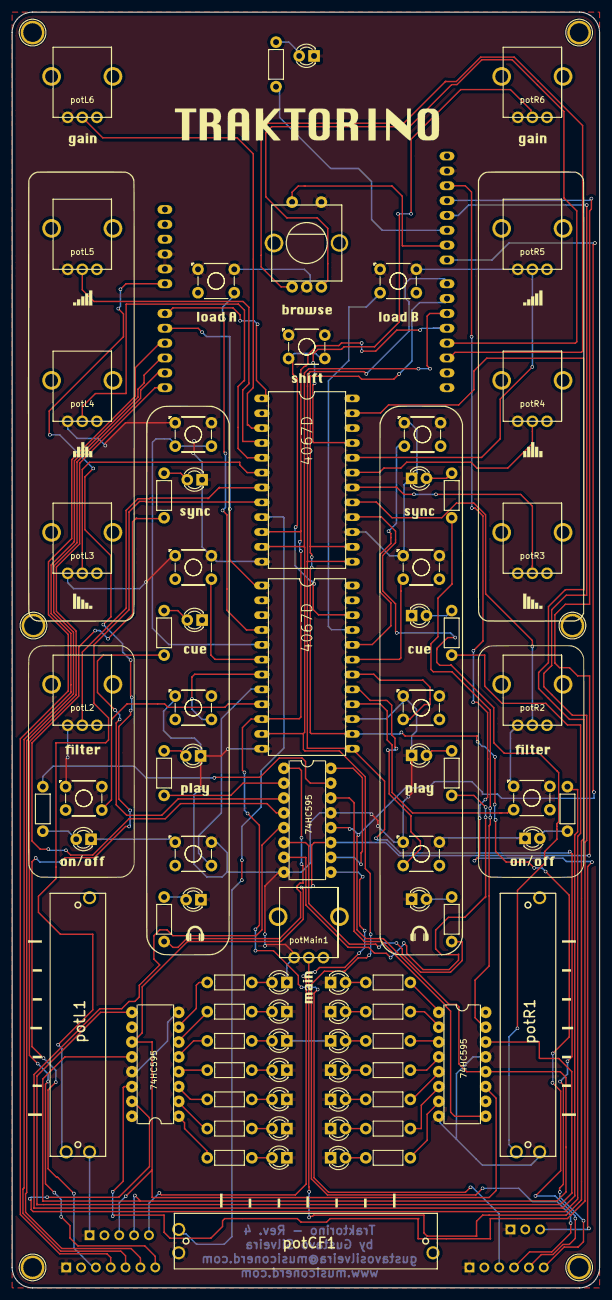
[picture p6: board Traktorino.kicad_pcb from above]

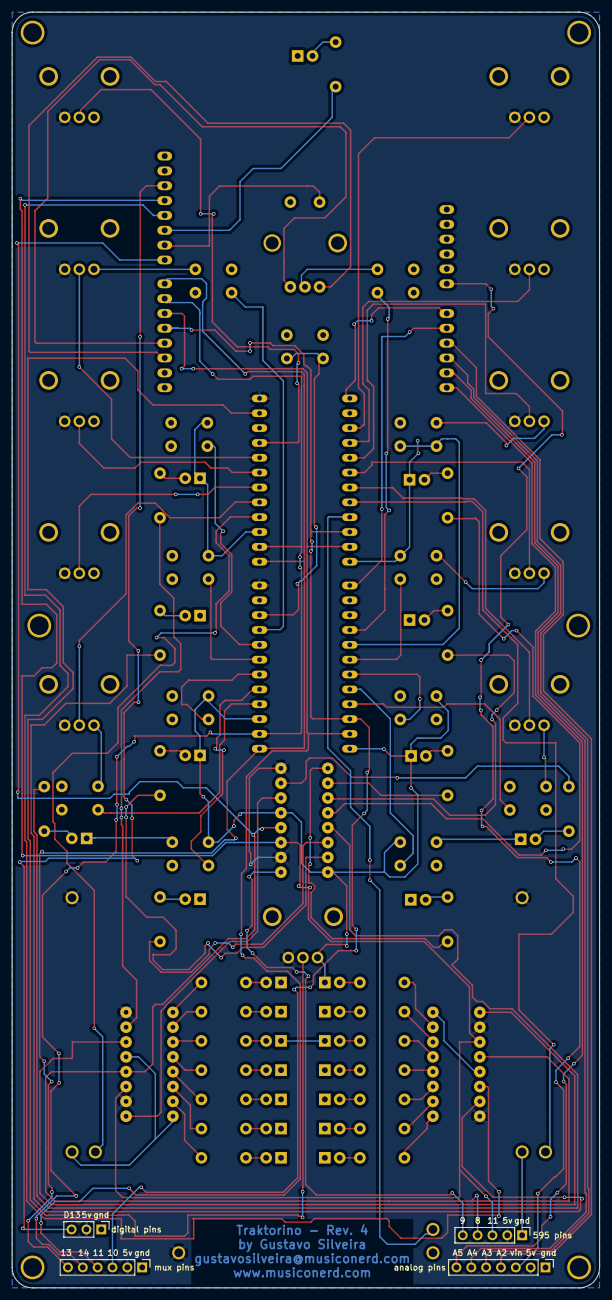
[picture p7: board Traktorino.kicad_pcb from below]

Board: 2 copper layers, 100.5 x 218.2 mm, 88 parts (4 on the bottom side), 100 nets.

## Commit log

2018-03-14 Traktorino files added
    [Traktorino 1-B.Cu.gbr, Traktorino 1-B.Mask.gbr, Traktorino 1-Edge.Cuts.gbr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]
2018-03-14 Gerber files
2018-04-27 gerber updated
    [Traktorino 1-B.Cu.gbr, Traktorino 1-B.Mask.gbr, Traktorino 1-Edge.Cuts.gbr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]
2018-06-15 Encoder fixed
2018-06-15 Encoder fixed
    And other bugs fixed
2018-06-16 Enclosure update
2018-07-02 PCB update
    Bigger solder masks for components. Some components had their legs spaced so they have a better fit.
    Free pins of the Arduino exposed.
    [Traktorino 1-B.Cu.gbr, Traktorino 1-B.Mask.gbr, Traktorino 1-F.Cu.gbr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]
2018-07-02 Gerber files updated
    [Traktorino rev 3-B.Cu.gbr, Traktorino rev 3-B.Mask.gbr, Traktorino rev 3-Edge.Cuts.gbr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]
2018-07-02 PCB updated
    Names added to the exposed pins.
    [Traktorino rev 3-B.Cu.gbr, Traktorino rev 3-B.Mask.gbr, Traktorino rev 3-Edge.Cuts.gbr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]
2018-07-02 pcb updated
    [Traktorino rev 3-B.Cu.gbr, Traktorino rev 3-B.Mask.gbr, Traktorino rev 3-B.SilkS.gbr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]
2018-07-06 Pdcb and enclosure update
    PCB rev. 4! Arduino and mux pins exposed.
    Enclosure's thongue was shortened so it doesn't collide with the chroma caps faders.
    [Traktorino rev 3-B.Cu.gbr, Traktorino rev 3-B.Mask.gbr, Traktorino rev 3-B.SilkS.gbr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]
2018-07-07 Enclosure update
    Put a missing "on/off".
    Adjusted the 12x24 sheet.
2018-07-09 Acrylic enclosure layout added
2020-03-24 fixes button reads from digital pins; enables browse encoder click
    added pinMode(..., INPUT_PULLUP) on buttons attached to digital pins in setup()
    added a button on pin 9 to enable browse encoder click detection
2020-04-13 Encoder click button added
2020-04-13 Encoder click added
2020-12-11 Kicad files added
    [Traktorino.kicad_pcb, Traktorino.sch]
2024-10-03 added 3mm info on the enclosure
